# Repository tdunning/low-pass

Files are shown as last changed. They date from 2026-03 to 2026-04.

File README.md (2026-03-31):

# 5th Order Chebyshev Low Pass Filter

This directory contains the design for a low-pass filter designed with
anti-aliasing in mind and laid out to avoid inadvertent coupling.

A typical use might be on the output of a direct synthesis chip such
as the AD9851. The DAC in an AD9851 is clocked at 180Ms/s which gives
rise to sampling noise at 180MHz. In addition, if you are generating a
waveform at frequency $f$, there will be an image in frequency space
of that output at $180MHz - f$. This filter is intended to suppress
such unwanted signals.

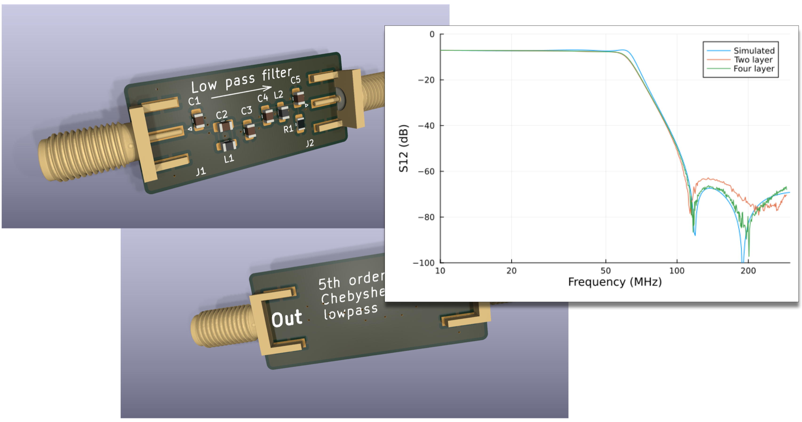
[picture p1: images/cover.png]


The circuit here is designed for the specific case of sampling at
180MHz and allowing outputs up to 60Mhz, while suppressing undesirable
outputs by at least 60dB. One of the filter poles is specially
adjusted to fall directly on the sampling frequency for maximum
suppression.

The design is also tuned to give very flat response for an output
impedance of 50 Ω. With a 1kΩ load, the passband response of the
filter alone can show variations in insertion loss of up to 3dB. To
minimize that effect, a 200Ω pre-load resistor is included in the
design. The stopband is relatively insensitive to variations in load.

The primary design here is a 4-layer board in order to minimize the
distance from the signal-carrying traces to the closest ground
plane. The design works nearly as well with a 2-layer board, but there
is noticeable degradation in performance as shown in the image above.

# Licensing

This project is licensed under the MIT license with the idea that the 
circuit designs and layouts are simply a form of software.

Please share and enjoy if you build something cool based on this work.

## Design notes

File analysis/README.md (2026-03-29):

# How Did It Work?

I constructed two versions of the filter, one with four layers and one
implemented with only two layers. Due to the simplicity of the
circuit, the only real different between the two versions was the
distance from the top layer where signal traces were located and the
nearest ground plane. In the four layer board, this distance is about
35μm while on the two layer version, it is about 1600 μm. This is
important because the area of a current loop formed by a
surface-mounted component and the associated return current in the
ground plan is 45 times larger in the case of the two layer board.

This larger area is directly proportional to how effective that
component is crating a magnetic. It is also directly proportional to
how effective a nearby component is at being affected by this
field. That means that the coupling between components is likely to be
2000 times stronger on the two layer board.

That higher coupling does not translate directly into performance that
is 2000 times worse. In many cases, the effect of this coupling is
negligible even if it is 2000 times stronger. The point of building
these two versions of the same board is precisely to see how important
this effect is in a practical setting.

# Data Acquisition

Both versions of the filter were characterized using a nanoVNA
(running firmware NanoVNA-H4 v1.2.27). This particular VNA exhibits
the well-known discontinuity effect when it switches to harmonic mode
at about 291 MHz. All measurements were made in a range from 50 kHz
to 290 MHz to avoid this effect. This range fortuitously matches the
desired range of operation for the filter.

Both S11 and S12 were measured using 10 measurement segments to
provide high resolution in frequency. The `s2p` files from the nanoVNA
were converted to `csv` format to create the `four-layer.csv` and
`two-layer.csv` files in this directory.

# Analysis

The Julia script `plot.jl` was used to put the theoretical and actual
results onto a single plot. Since the theoretical results included the
loss caused by source and load impedances and the nanoVNA compensated
for this loss, the measured results were adjusted to compensate by
offsetting them by -6dB.

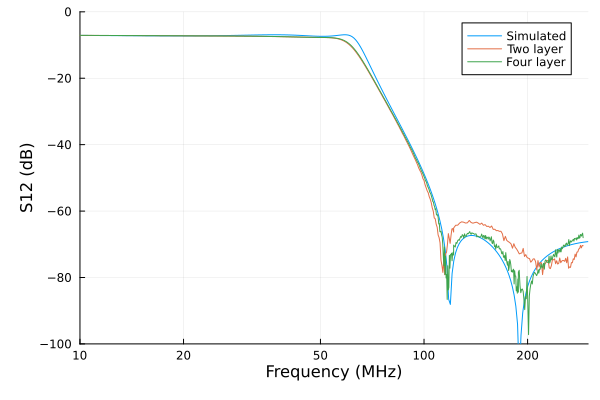
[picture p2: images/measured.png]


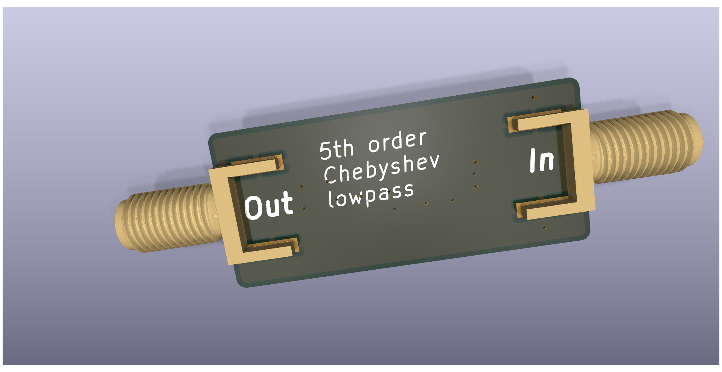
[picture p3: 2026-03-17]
images/render2.png

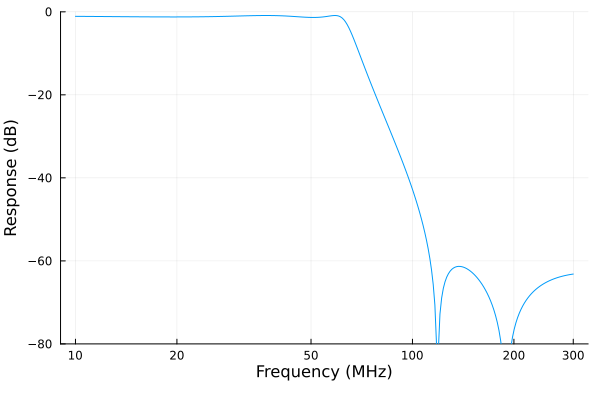
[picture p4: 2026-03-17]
images/response.png

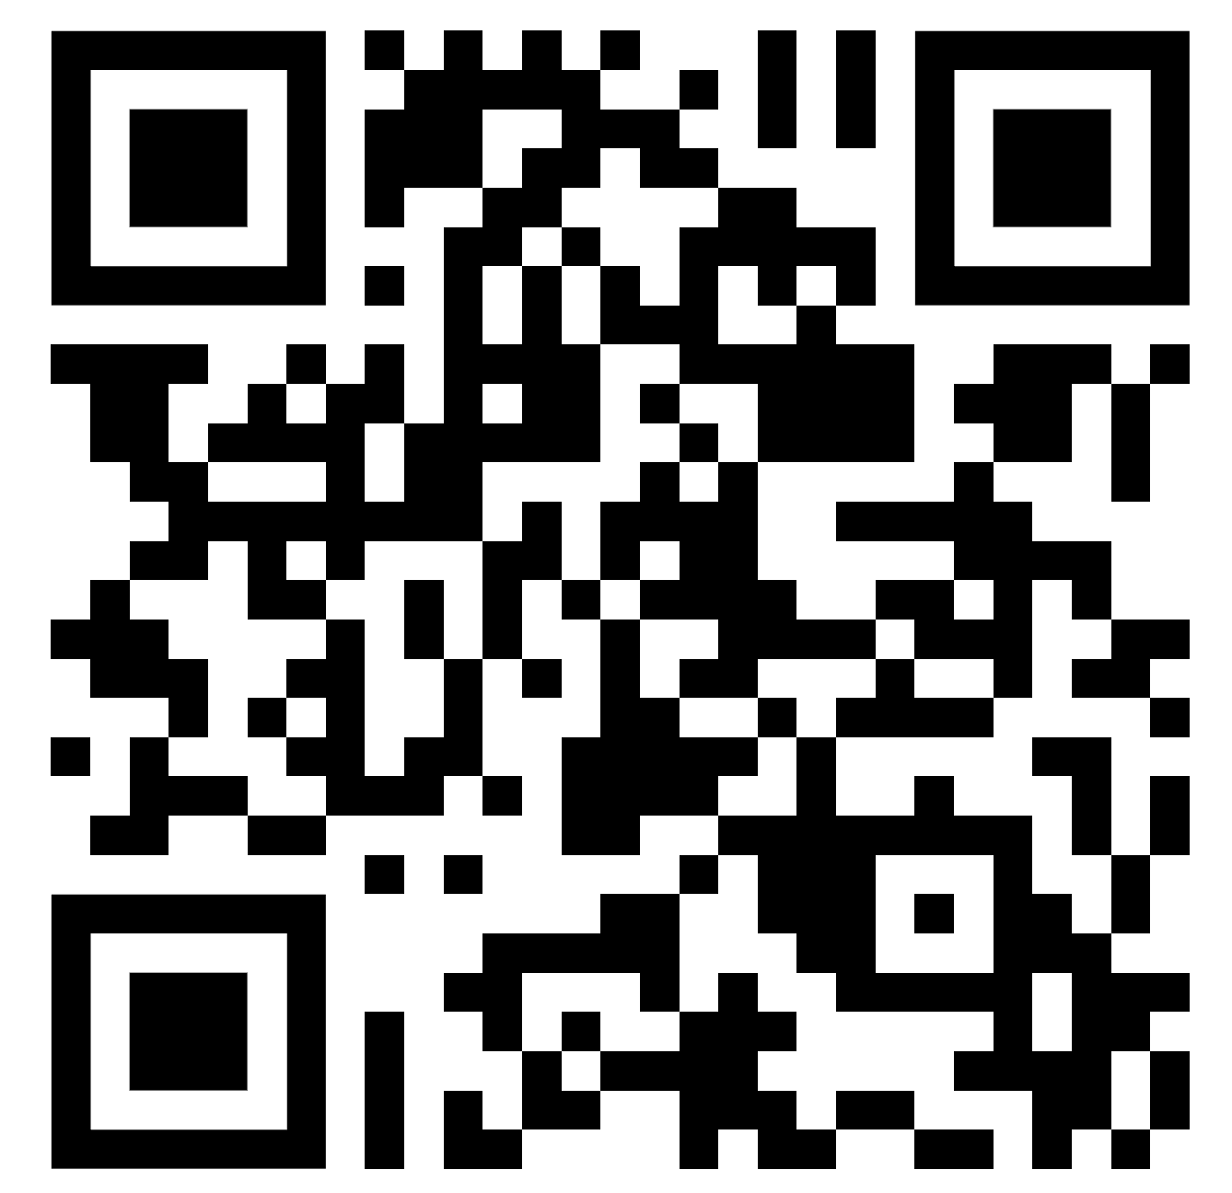
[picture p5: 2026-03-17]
images/qr.png

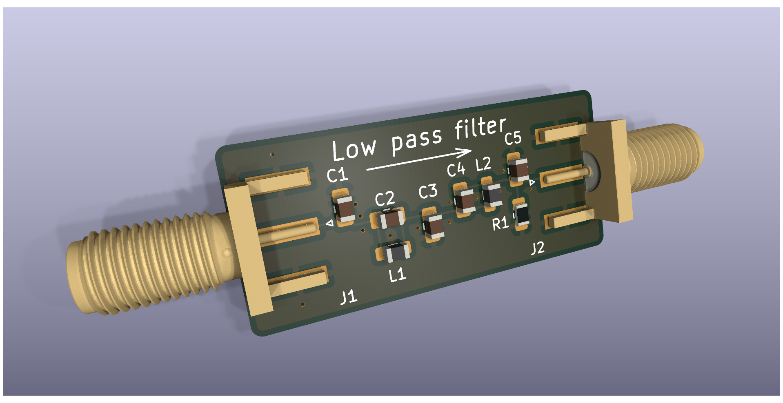
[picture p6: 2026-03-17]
images/render1.png

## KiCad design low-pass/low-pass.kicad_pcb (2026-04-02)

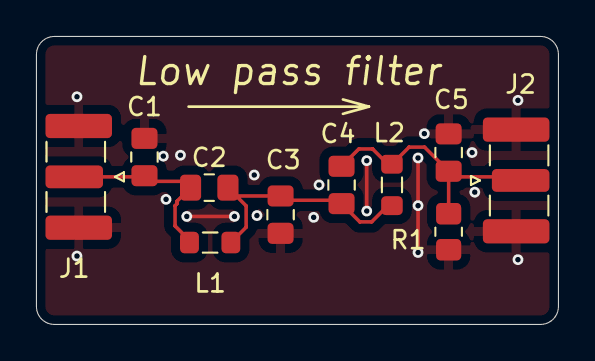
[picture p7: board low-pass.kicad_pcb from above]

Board: 4 copper layers, 29.0 x 16.0 mm, 10 parts (0 on the bottom side), 4 nets.

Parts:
C1, C5: 82p; C_0805_2012Metric_Pad1.18x1.45mm_HandSolder
C2: 4.7p; C_0805_2012Metric_Pad1.18x1.45mm_HandSolder
C3: 120p; C_0805_2012Metric_Pad1.18x1.45mm_HandSolder
C4: 15p; C_0805_2012Metric_Pad1.18x1.45mm_HandSolder
J1, J2: Conn_Coaxial; SMA_Samtec_SMA-J-P-H-ST-EM1_EdgeMount
L1: 150n; L_0805_2012Metric_Pad1.05x1.20mm_HandSolder
L2: 120n; L_0805_2012Metric_Pad1.05x1.20mm_HandSolder
R1: 220; R_0805_2012Metric_Pad1.20x1.40mm_HandSolder

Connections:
GND: C1.2, C3.2, C5.2, J1.2 (Ext), J2.2 (Ext), R1.2
unnamed: C2.2, C3.1, C4.1, L1.2, L2.1
unnamed: C1.1, C2.1, J1.1 (In), L1.1
unnamed: C4.2, C5.1, J2.1 (In), L2.2, R1.1

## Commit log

2026-03-17 Added QR code to back
    [low-pass.kicad_pcb]
2026-03-29 Added two layer version and experimental results
    [four-layer.csv, low-pass.kicad_pcb, low-pass.kicad_sch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]
2026-03-29 Improved (I think) the two layer layout
    [low-pass.kicad_pcb]
2026-04-02 Slight updates to the layout for possible improvement in isolation of components
    [low-pass.kicad_pcb, low-pass.kicad_sch]
